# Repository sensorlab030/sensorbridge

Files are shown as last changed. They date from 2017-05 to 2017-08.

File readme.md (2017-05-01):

# Sensor Bridge

The sensor bridge board is a small piece of embedded hardware that allows the 
user to easily connect up to six analog sensors. The board will then read the 
data from the sensors and send this data via the serial port to a [client 
application](https://github.com/sensorlab030/sensorbridge-client) which then
either records the data to files or serves it over a websocket to interested
applications.

The firmware (/firmware) of the sensor board is [Arduino](https://www.arduino.cc/) 
based and the board layout files (/hardware) are created with 
[CadSoft/Autodesk Eagle](http://www.autodesk.com/products/eagle/overview)

## Protocol

The data from the sensors is sent over the serial port at a baud rate of 9600 
bps. 

The serial protocol in which the data is communicated is very straighforward: 
it will always send six two-byte (16 bit) values (ordered from sensor one to 
sensor six), separated by a carriage return (```0x0D```) and a line feed 
(```0x0A```). So one single message will always be 14 bytes long and  be ordered 
like this:

```
Sensor 1 value | Sensor 2 value | Sensor 3 value | Sensor 4 value |
Sensor 5 value | Sensor 5 value | Carriage return | Line feed
```

The sensor readings will have a value from 0 to 1023 (10 bit), and will be 
sent with the high byte first. If it is detected that there is no sensor 
connected to the analog input, a value of ```FF:FF``` will be sent to notify the 
disconnected state of the sensor.

### Example 1: One sensor connected, analog value of 0

This is the message that is sent when only the first sensor is connected that
has a sensor reading of 0 (```00:00```).

```
00:00:FF:FF:FF:FF:FF:FF:FF:FF:FF:FF:0D:0A
```

### Example 2: One sensor connected, analog value of 1023

This is the message that is sent when only the first sensor is connected that
has a sensor reading of 1023 (```03:FF```).

```
03:FF:FF:FF:FF:FF:FF:FF:FF:FF:FF:FF:0D:0A
```

## License

The firmware (everything under /firmware) is licensed under the GPLv3, the 
Arduino core libraries and IDE are under their own respective licenses (GNU 
LGPL and GNU GPL). License text can be found under /firmware/license.txt

The board layout files (everything under /hardware) is under the Creative 
Commons Attribution-ShareAlike 3.0 Unported License. License text can be 
found under /hardware/license.txt

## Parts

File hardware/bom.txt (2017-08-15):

Part               Description                            Value              Octopart link
ARDUINO_ANALOG     1x6 0.1 inch male header               NA                 https://octopart.com/22-28-4090-molex-278177
ARDUINO_DIGITAL    1x8 0.1 inch male header               NA                 https://octopart.com/22-28-4090-molex-278177
ARDUINO_SUPPLY     1x3 0.1 inch male header               NA                 https://octopart.com/22-28-4090-molex-278177
INPUT_1            JST 5 position 2mm Pitch connector     NA                 https://octopart.com/s5b-ph-k-s%28lf%29%28sn%29-jst-248886
INPUT_2            JST 5 position 2mm Pitch connector     NA                 https://octopart.com/s5b-ph-k-s%28lf%29%28sn%29-jst-248886
INPUT_3            JST 5 position 2mm Pitch connector     NA                 https://octopart.com/s5b-ph-k-s%28lf%29%28sn%29-jst-248886
LED1               0603 LED (green)                       NA                 https://octopart.com/sml-d12m8wt86-rohm-8992277
LED2               0603 LED (green)                       NA                 https://octopart.com/sml-d12m8wt86-rohm-8992277
LED3               0603 LED (green)                       NA                 https://octopart.com/sml-d12m8wt86-rohm-8992277
PWR_LED            0603 LED (green)                       NA                 https://octopart.com/sml-d12m8wt86-rohm-8992277
R1                 0603 resistor                          470                https://octopart.com/cr0603-fx-4700elf-bourns-3825414
R2                 0603 resistor                          470                https://octopart.com/cr0603-fx-4700elf-bourns-3825414
R3                 0603 resistor                          470                https://octopart.com/cr0603-fx-4700elf-bourns-3825414
R4                 0603 resistor                          10K                https://octopart.com/cr0603-fx-1002elf-bourns-2326648
R5                 0603 resistor                          10K                https://octopart.com/cr0603-fx-1002elf-bourns-2326648
R6                 0603 resistor                          10K                https://octopart.com/cr0603-fx-1002elf-bourns-2326648
R8                 0603 resistor                          470                https://octopart.com/cr0603-fx-4700elf-bourns-3825414

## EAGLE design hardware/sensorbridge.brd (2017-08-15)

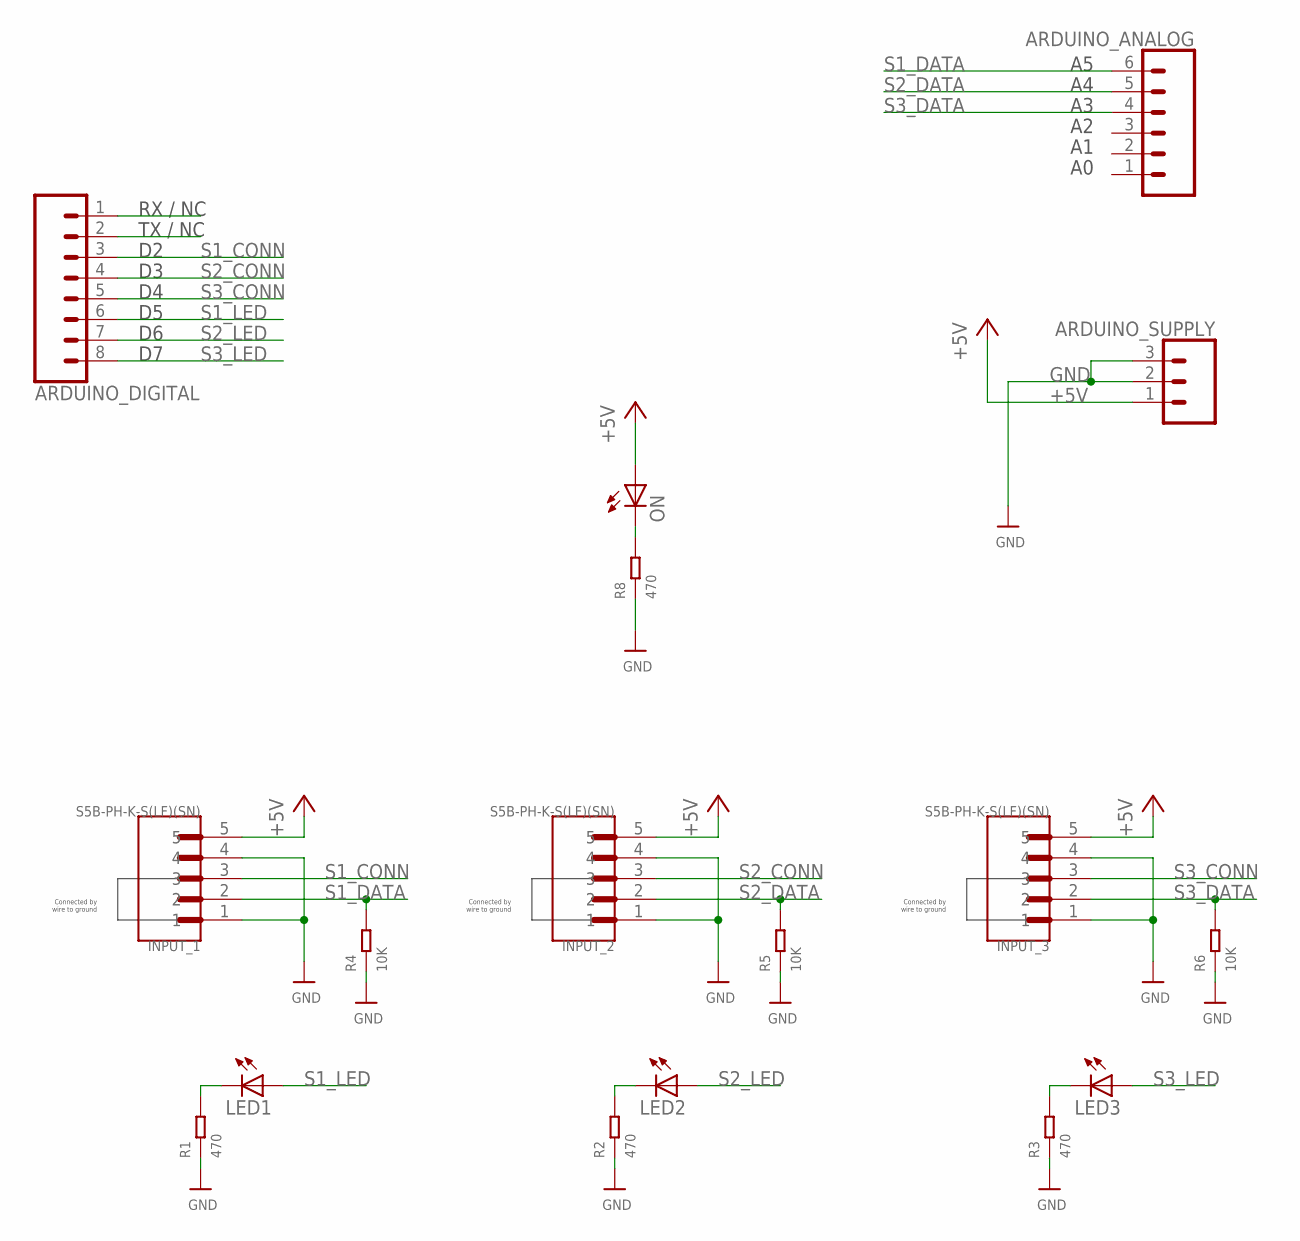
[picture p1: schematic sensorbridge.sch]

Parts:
ARDUINO_ANALOG: CONN_06NO_SILK_FEMALE_PTH; 1X06_NO_SILK
ARDUINO_DIGITAL: CONN_08NO_SILK_FEMALE_PTH; 1X08_NO_SILK
ARDUINO_SUPPLY: CONN_031X03_NO_SILK; 1X03_NO_SILK
INPUT_1, INPUT_2, INPUT_3: S5B-PH-K-S(LF)(SN); JST_S5B-PH-K-S(LF)(SN)
LED1, LED2, LED3: LEDCHIP-LED0603; CHIP-LED0603
ON: LEDCHIP-LED0603; CHIP-LED0603
R1, R2, R3, R8: 470; R0603
R4, R5, R6: 10K; R0603

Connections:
+5V: ARDUINO_SUPPLY.1, INPUT_1.5, INPUT_2.5, INPUT_3.5, ON.A
GND: ARDUINO_SUPPLY.2, ARDUINO_SUPPLY.3, INPUT_1.1, INPUT_1.4, INPUT_2.1, INPUT_2.4, INPUT_3.1, INPUT_3.4, R1.1, R2.1, R3.1, R4.1, R5.1, R6.1, R8.1
unnamed: LED1.C, R1.2
unnamed: LED2.C, R2.2
unnamed: LED3.C, R3.2
unnamed: ON.C, R8.2
S1_CONN: ARDUINO_DIGITAL.3, INPUT_1.3
S1_DATA: ARDUINO_ANALOG.6, INPUT_1.2, R4.2
S1_LED: ARDUINO_DIGITAL.6, LED1.A
S2_CONN: ARDUINO_DIGITAL.4, INPUT_2.3
S2_DATA: ARDUINO_ANALOG.5, INPUT_2.2, R5.2
S2_LED: ARDUINO_DIGITAL.7, LED2.A
S3_CONN: ARDUINO_DIGITAL.5, INPUT_3.3
S3_DATA: ARDUINO_ANALOG.4, INPUT_3.2, R6.2
S3_LED: ARDUINO_DIGITAL.8, LED3.A

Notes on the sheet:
RX / NC
TX / NC
Connected by wire to ground

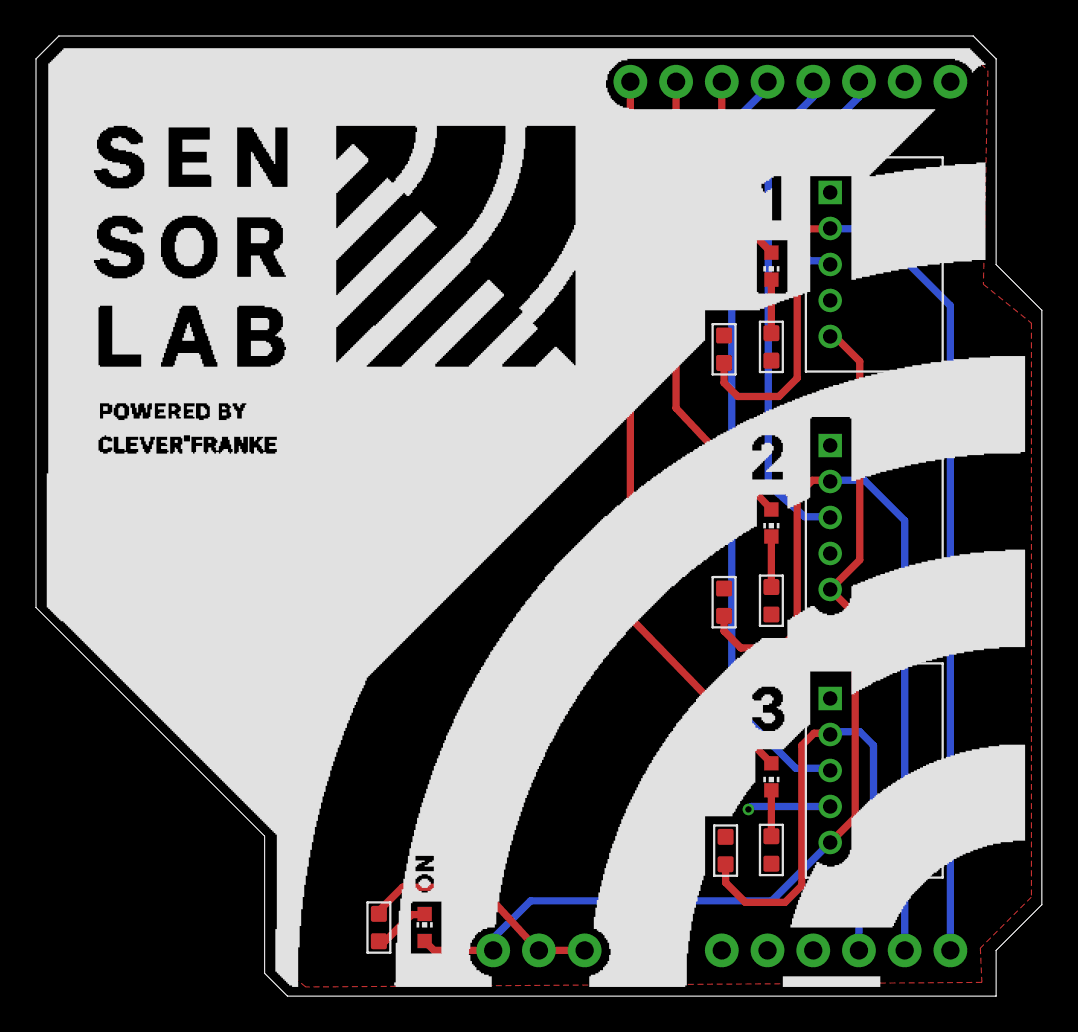
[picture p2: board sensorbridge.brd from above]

Board: 2 copper layers, 55.9 x 53.3 mm, 17 parts (0 on the bottom side), 15 nets.

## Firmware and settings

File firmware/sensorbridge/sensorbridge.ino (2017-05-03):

#define SENSOR_COUNT 6
#define STATUS_LED_PIN 7

// Mapping of sensors to pins. The first value of the sensor pin arrays
// is the pin that Sensor1 is connected to, second value for Sensor2 and
// so on.
//                       Sensor id: 1, 2, 3, 4, 5, 6
uint8_t sensorDataPins[]        = { 5, 4, 3, 2, 0, 1 }; // Analog input pin the sensor is connected to
uint8_t sensorConnectionPins[]  = { 4, 5, 6, 7, 3, 2 }; // Digital input pin the sensor is connected to

void setup() {

  // Setup pin modes for the connection pins
  for (int i = 0; i < SENSOR_COUNT; i++) {
    pinMode(sensorConnectionPins[i], INPUT);
  }
  pinMode(STATUS_LED_PIN, OUTPUT);

  // Start serial communication
  Serial.begin(9600);
  
}

void loop() {

  // Read and communicate values
  for (int i = 0; i < SENSOR_COUNT; i++) {

    // Determine value of pin
    bool sensorConnected = digitalRead(sensorConnectionPins[i]);
    uint16_t value = sensorConnected ? analogRead(sensorDataPins[i]) : 65535;

    // Write value to serial port
    Serial.write(highByte(value));
    Serial.write(lowByte(value));
    
  }
  
  // Terminate series of values
  Serial.write(0x0D);
  Serial.write(0x0A);

  // Wait for a bit
  delay(20);
  
}

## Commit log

2017-05-02 Added initial hardware files
    [sensorbridge.brd, sensorbridge.sch]
2017-05-02 Updated board layout, replaced jack, added status led
    [sensorbridge.brd, sensorbridge.sch]
2017-05-03 Adapted shield outline
    [sensorbridge.brd, sensorbridge.sch]
2017-05-03 Added power led
    [sensorbridge.brd, sensorbridge.sch]
2017-05-03 Added arduino pin names to info layer
    [sensorbridge.brd, sensorbridge.sch]
2017-05-03 Digital pin reconfiguration
    [sensorbridge.brd, sensorbridge.sch]
2017-05-03 Tweaked board dimensions
    [sensorbridge.brd, sensorbridge.sch]
2017-05-03 Replaced header parts for headers with silkscreen
    [sensorbridge.brd, sensorbridge.sch]
2017-05-17 Added top and bottom silks
    [sensorbridge.brd, sensorbridge.sch]
2017-05-17 Added ground planes, fixed DRC errors (dirtypcb)
    [sensorbridge.brd, sensorbridge.sch]
2017-05-17 Replaced connectors with no-silk versions
    [sensorbridge.brd, sensorbridge.sch]
2017-07-31 Changed connectors, made LED pin-controlled
    [sensorbridge.sch]
2017-08-15 Made sensor connection through GND instead of VCC, added pulldown resistors to DATA lines
    [sensorbridge.brd, sensorbridge.sch]

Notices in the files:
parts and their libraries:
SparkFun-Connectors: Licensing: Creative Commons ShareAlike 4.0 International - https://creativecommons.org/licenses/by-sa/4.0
